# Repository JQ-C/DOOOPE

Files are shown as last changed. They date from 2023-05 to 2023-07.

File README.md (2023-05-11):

# DOOOPE. Real or Fake?
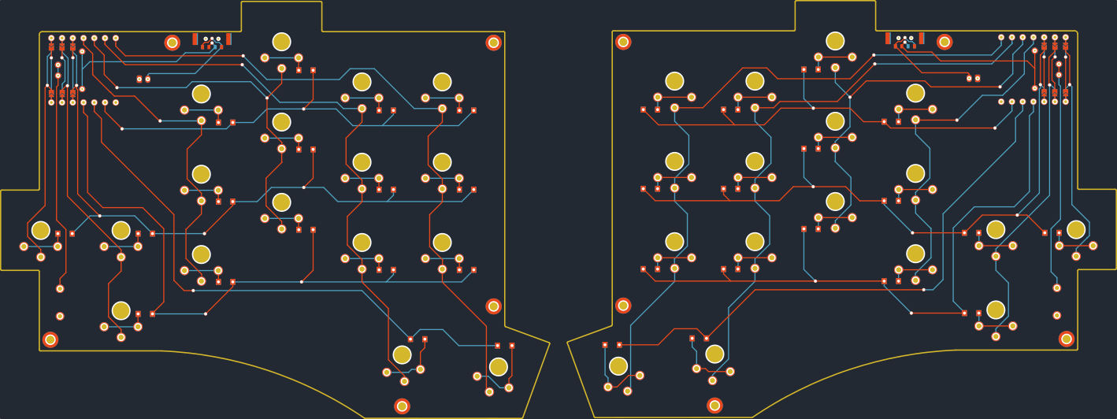
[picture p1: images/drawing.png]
pcb svg

DOOOPE Keyboard is a 34-key wireless split keyboard. That uses Redragon low profile switches.

## Design Philosophy
DOOOPE was created with these in mind
- Budget at each category (MCU, Switch, Keycaps)
- Modular & Reusable parts
- Low Cost
- Low Profile
- Wireless
- 34 keys

# Resources

[Here](Kicad) you can find the Kicad files. 
<br>
[ZMK Config](https://github.com/JQ-C/zmk-config) for the DOOOPE using Xiao BLe

# Bill of Material
The link provided will be actual store i bought from but not affiliated with.
|Component|Amount|Remarks|Link|
|:----|:----|:----|:----|
|DOOOPE PCB|2|-| |
|SEEED Xiao BLE|2|-|[Cytron](https://my.cytron.io/p-seeed-xiao-ble-nrf52840-bluetooth-5p0)|
|Rechargeable Battery|2|28 x 18mm max| |
|Reset Switch|2|Through hole| |
|Power Switch|2|MSK12C02| [Shopee](https://shopee.com.my/10PCS-Slide-Switch-Micro-power-Toggle-Switch-Single-and-Double-row-Direct-inserted-Horizontal-Sliding-Second-Gear-Third-Gear-i.313127058.366153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)|
|Pogo Pins|4|5mm|[Aliexpress](https://www.aliexpress.com/item/1005004016701633.html)|
|Redragon Switches|34|5mm|[Shopee](https://shopee.com.my/Redragon-SMD-RGB-MX-Low-Profile-Switch-3-Pin-for-Keyboard-Red-Black-Blue-Brown-i.326526863.10495732994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)|
|2mm male socket pins|4|1x7| |
|2.54 machine header pins|4|1x7| |
|JST PH 2.0 Connetor|2 Pair |-|[Shopee](https://shopee.com.my/10Sets-Lot-PH2.0-PH-2mm-Connector-Straight-needle-Seat-Plug-Terminals-2P-3P-4P-5P-6P-7P-8P-9P-10P-Connector-Pitch-2.0-i.313127058.5356644366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)|

# Build Guide
Coming soon <br>
The build guide for the DOOOPE keyboard can be found [here]()

# Project Reason
- DOOOPE keyboard was created to use Redragon low profile switch as a cheap alternative to the Low profile choc switches used in many Low-pro boards, hence the name "DOOOPE" that sounds like dupe.
- Another decision is to use off the shelf components and the cheapest at each category.
- This keyboard also used [Ergogen V4]() to prototype the layout and later finished in Kicad.

# Credits & Learning Resources

## Credits
1. Overall inspiration is the execellent keyboard [Totem by GEIST](https://github.com/GEIGEIGEIST/TOTEM)
2. The exposed copper art is inspired by [Urchin by Kyek](https://github.com/duckyb/urchin)
3. The special "negative silkscreen" and overall silkscreen style by [Dilemma by bastardkb](https://github.com/Bastardkb/Dilemma)
4. Pogo pin footprint from [Tlalocohyla Smithii by LuarRaNa](https://github.com/LuarRaNa/tlalocohyla_smithii)
5. Switch and much more footprint from [FingerPunch by SadekBaroudi](https://github.com/sadekbaroudi/fingerpunch)

I also want to thank the very helpful people in the [FingerPunch Discord]() that help guide me with the PCB creation.

## Learning Resources
The execellent [Ergogen Guide](https://web.archive.org/web/20230508055048/https://flatfootfox.com/ergogen-introduction/) by @FlatFootFox from the [Ergogen Discord](http://discord.ergogen.xyz/). Fall into the rabbit hole now with [Ergogen WebUI](https://ergogen.cache.works/). <br>

Great Non-keyboard Kicad Guide to get comfortable with the tool [STM32 PCB Design by Phils Lab](https://www.youtube.com/watch?v=aVUqaB0IMh4).

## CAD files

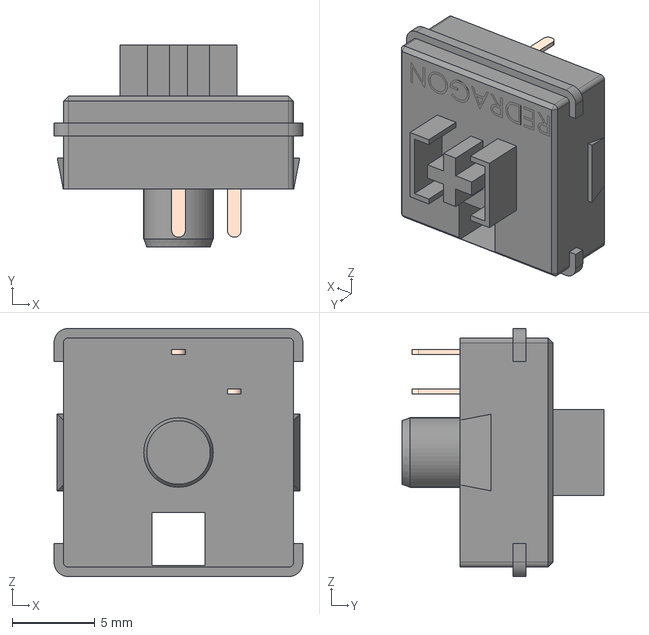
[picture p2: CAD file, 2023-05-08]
Kicad/KB3D/Btn_redragon_flat.step
15.0 x 12.2 x 15.0 mm

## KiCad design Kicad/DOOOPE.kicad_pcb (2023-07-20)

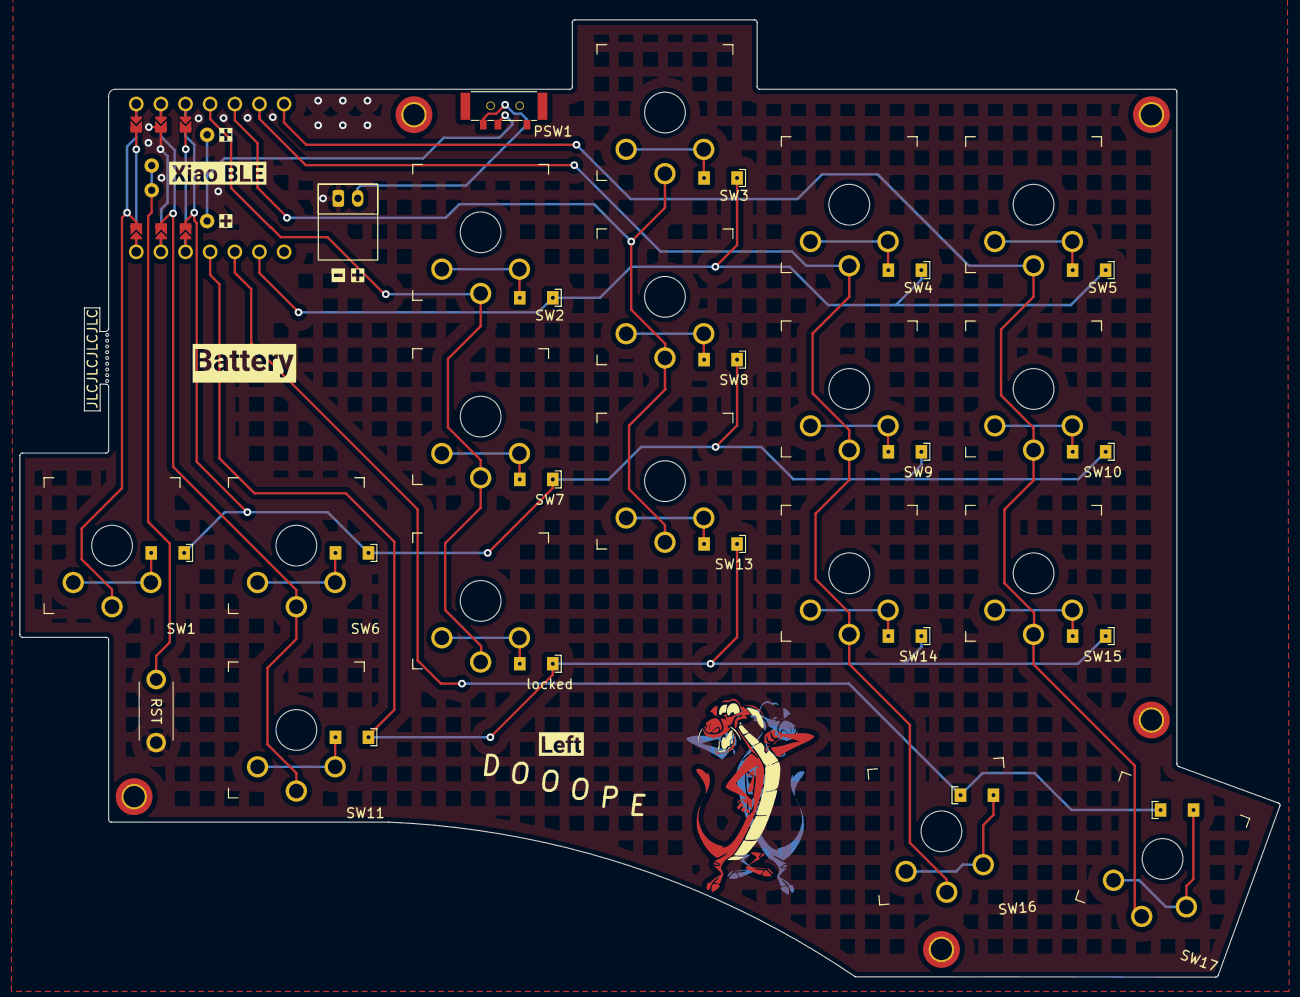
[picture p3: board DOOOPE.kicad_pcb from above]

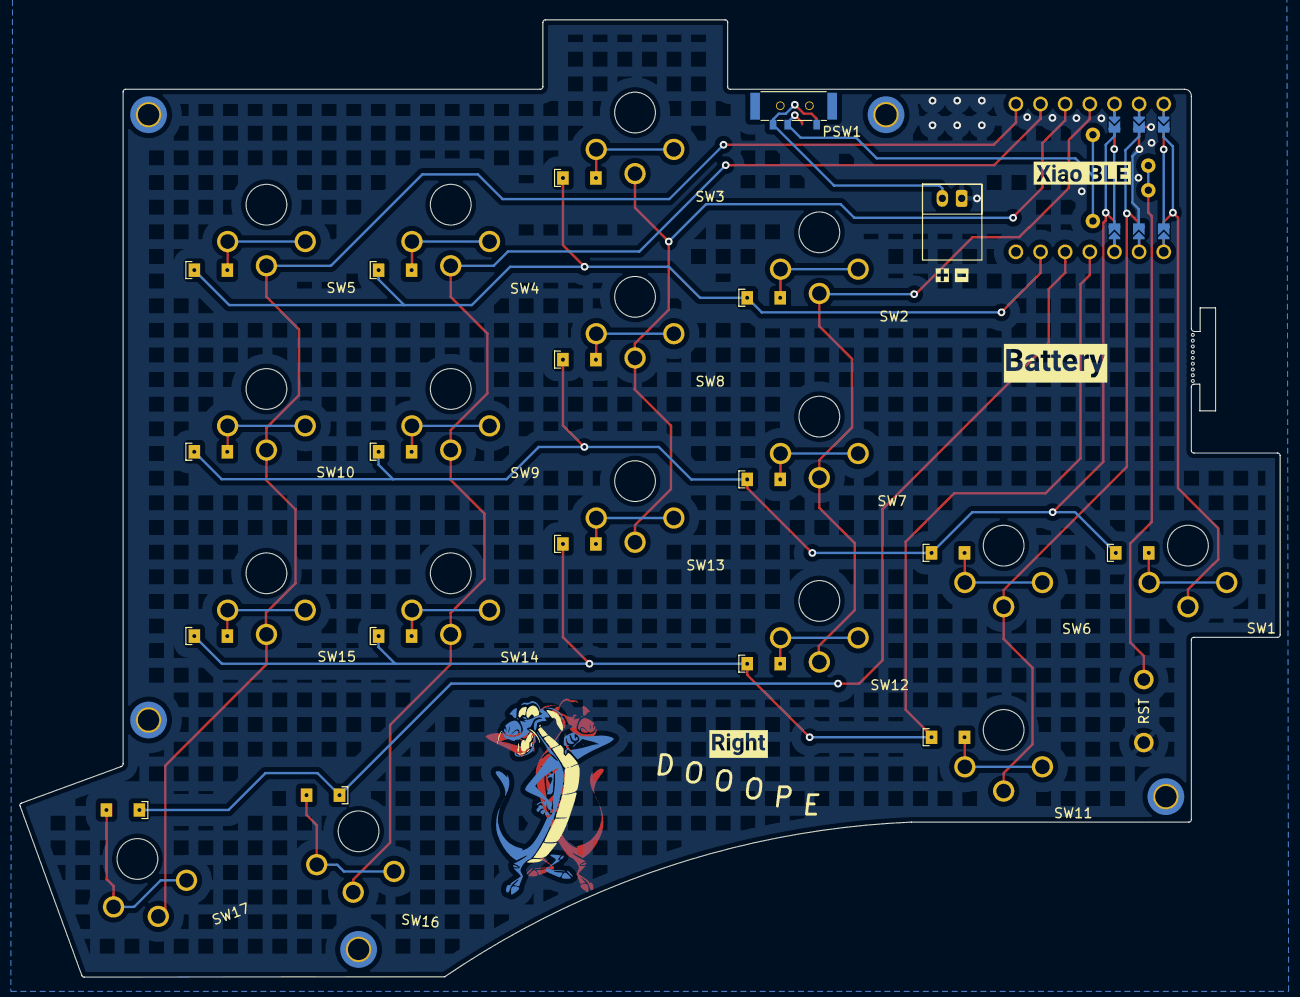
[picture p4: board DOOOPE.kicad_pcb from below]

Board: 2 copper layers, 129.9 x 98.7 mm, 51 parts (6 on the bottom side), 31 nets.

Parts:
D1, D2, D3, D4, D5, D6, D7, D8, D9, D10, D11, D12, D13, D14, D15, D16, D17: 1N4148W; Diode SMD THT
J2: JST Connector; JST_PH_S2B-PH-K_1x02_P2.00mm_Horizontal
PSW1, PSW1#2: SW_SPDT; Power Switch
S1: 95C04A3T; Reset Switch
SW1, SW2, SW3, SW4, SW5, SW6, SW7, SW8, SW9, SW10, SW11, SW13, SW14, SW15, SW16, SW17: SW_PUSH; Redragon_LP_Reversible
U1: xiao-ble; Xiao BLE Rev Pogo
kibuzzard-643B780C: G***; kibuzzard-643B780C
kibuzzard-643B7631, kibuzzard-643B7631#2: G***; kibuzzard-643B7631
kibuzzard-643B7841: G***; kibuzzard-643B7841
kibuzzard-643B7985, kibuzzard-643B7985#2, kibuzzard-643B7985#3, kibuzzard-643B7985#4: G***; kibuzzard-643B7985
kibuzzard-6465F412, kibuzzard-6465F412#2: G***; kibuzzard-6465F412
kibuzzard-6465FBCD, kibuzzard-6465FBCD#2: G***; kibuzzard-6465FBCD
locked: SW_PUSH; Redragon_LP_Reversible

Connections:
BAT+: PSW1.2 (B), PSW1#2.2 (B), U1.19 (BAT)
Col0: SW1.1, U1.1 (A2/0.02_H)
Col1: SW6.1, SW11.1, U1.2 (A4/0.03_H)
Col2: SW2.1, SW7.1, U1.11 (A6_MOSI/1.15), locked.1
Col3: SW3.1, SW8.1, SW13.1, U1.10 (A5_MISO/1.14)
Col4: SW4.1, SW9.1, SW14.1, SW16.1, U1.9 (A7_SCK/1.13)
Col5: SW5.1, SW10.1, SW15.1, SW17.1, U1.8 (B9_RX/1.12)
GND: J2.1, S1.T2 (NO), U1.13 (GND)
unnamed: D1.2 (A), SW1.2
unnamed: D2.2 (A), SW2.2
unnamed: D3.2 (A), SW3.2
unnamed: D4.2 (A), SW4.2
unnamed: D5.2 (A), SW5.2
unnamed: D6.2 (A), SW6.2
unnamed: D7.2 (A), SW7.2
unnamed: D8.2 (A), SW8.2
unnamed: D9.2 (A), SW9.2
unnamed: D10.2 (A), SW10.2
unnamed: D11.2 (A), SW11.2
unnamed: D12.2 (A), locked.2
unnamed: D13.2 (A), SW13.2
unnamed: D14.2 (A), SW14.2
unnamed: D15.2 (A), SW15.2
unnamed: D16.2 (A), SW16.2
unnamed: D17.2 (A), SW17.2
RST: S1.T1 (COM), U1.17 (RESET)
Row0: D2.1 (K), D3.1 (K), D4.1 (K), D5.1 (K), U1.6 (A9_SCL/0.05_H)
Row1: D1.1 (K), D6.1 (K), D7.1 (K), D8.1 (K), D9.1 (K), D10.1 (K), U1.3 (A10/0.28)
Row2: D11.1 (K), D12.1 (K), D13.1 (K), D14.1 (K), D15.1 (K), U1.4 (A11/0.29)
Row3: D16.1 (K), D17.1 (K), U1.5 (A8_SDA/0.04_H)
VBAT: J2.2, PSW1.3 (C), PSW1#2.3 (C)

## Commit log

2023-05-08 Restructure project into Rev 1 & 2
    [DOOOPE-B_Cu.gbl, DOOOPE-B_Mask.gbs, DOOOPE-B_Paste.gbp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]
2023-05-08 Added R2 kicad files
    [Btn_redragon_flat.step, DOOOPE.kicad_pcb, DOOOPE.kicad_sch]
2023-05-11 Restructure repo
    [Btn_redragon_flat.step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]
2023-05-11 Update read me
    [Btn_redragon_flat.step, DOOOPE.kicad_pcb, DOOOPE.kicad_sch]
2023-07-20 latest files
    [DOOOPE.kicad_pcb]
